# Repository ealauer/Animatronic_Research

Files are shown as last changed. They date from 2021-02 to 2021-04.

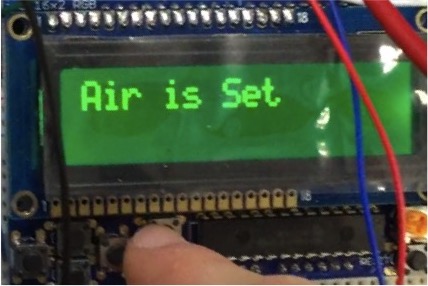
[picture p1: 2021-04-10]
UI Flow Pictures/5AirSet.jpg

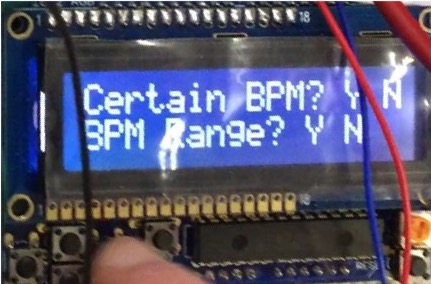
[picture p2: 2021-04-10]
UI Flow Pictures/6Pulse.jpg

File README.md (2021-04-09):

# Humanoid Animatronic Learning Simulator for Medical Interactive Training (H.A.L. S.M.I.T., or HAL for short)
Created by Ethan Lauer, Master of Science Robotics Engineering, Class of 2021, Worcester Polytechnic Institute (WPI)

Advised by Professor Pradeep Radhakrishnan, Department of Mechanical and Robotics Engineering, Worcester Polytechnic Institute (WPI)

Last Edited Spring 2021.

# Introduction
Medical simulation is becoming more prominent in the medical community as it provides a highly realistic and beneficial training experience. The technology is expensive for low-budget medical programs, and manikins have limited capacity for complex tasks. This project addressed such gaps by producing a low-cost head and neck animatronic prototype capable of performing complex simulations. The target simulations for the manikin included airway management, level of consciousness testing, and circulatory assessment. Major facial features were designed so the mechanical systems could exhibit anthropomorphic characteristics. Sensors were integrated into the design, allowing the animatronic to detect and react to changes in the surrounding environment. The subsystems were constructed and tested, however, challenges were faced during full assembly. Despite these challenges, the design demonstrates the potential for a similar application in the medical field. This GitHub repository contains the code, circuit diagrams, and CAD files for HAL.

# Initial Information
Be sure to install the latest version of Arduino (https://www.arduino.cc/en/software) and the Teensy Loader (https://www.pjrc.com/teensy/loader.html) before uploading the code.

Follow the steps detailed in the manual and note the comments in the official when working on H.A.L.

# Folder Descriptions
The folder titled "HAL" contains all of the Arduino code to control HAL.

The folder titled "MATLAB" contains the code and calculations for the possible Stewart platform neck design. This also includes the resulting plots and .xls files of the servo angles necessary for various movements.

The folder titled "New Neck Test" contains area where Arduino code could be developed for the Stewart platform.

The "WaveFilePlayerV1" folder contains the test file for playing pre-recorded audio from a microSD card in the Teensy using the Audio Library.

The folder titled "SolidWorks Files" contains the CAD files for the full system. The Skin CAD files are very large and can be found here (https://drive.google.com/drive/folders/1OjMSTwuhYAyCOeIsZ3wJBqHO3pZZC7u_?usp=sharing).

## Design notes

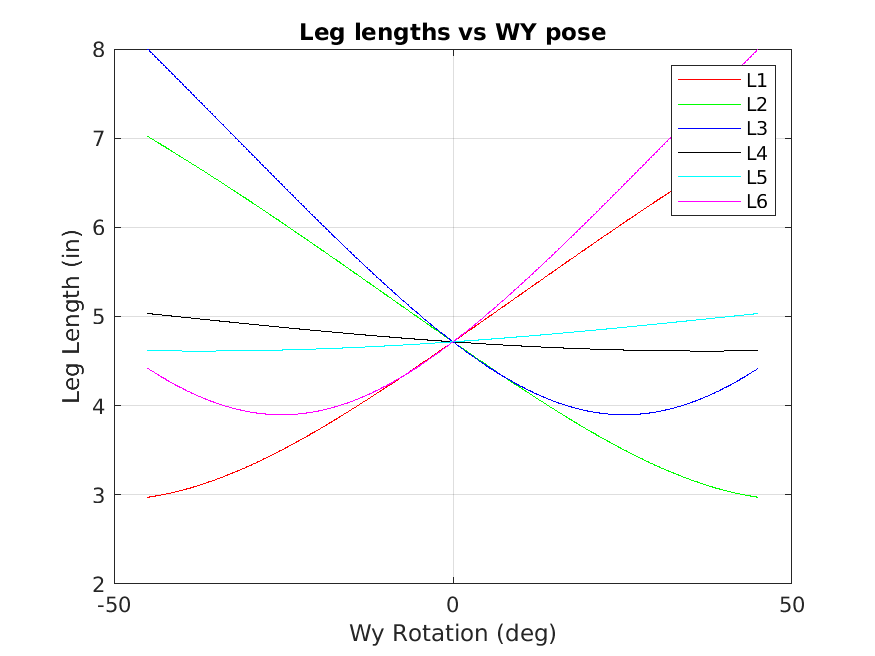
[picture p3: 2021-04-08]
MATLAB/figLegLengthWYPose.png

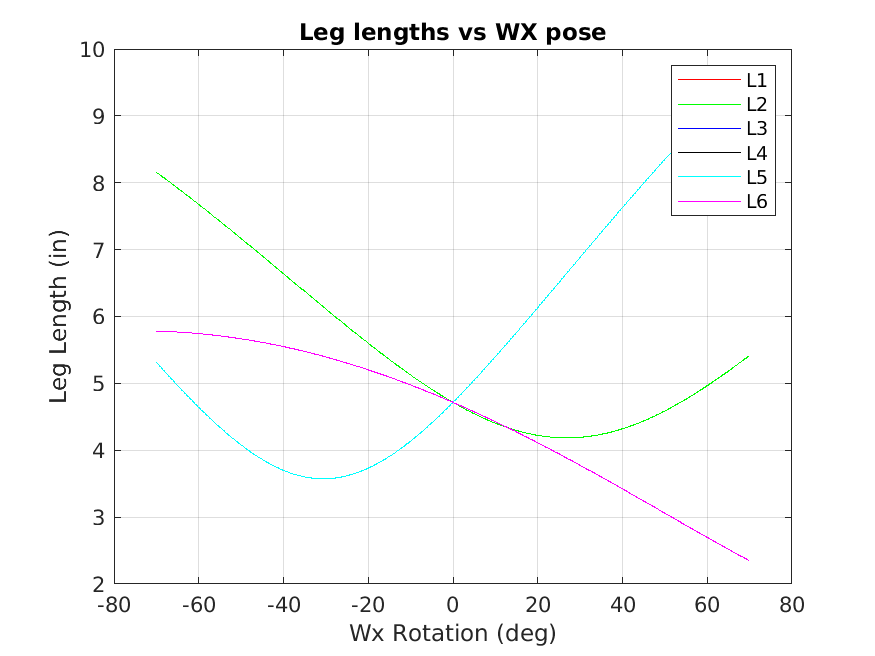
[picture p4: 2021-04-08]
MATLAB/figLegLengthWXPose.png

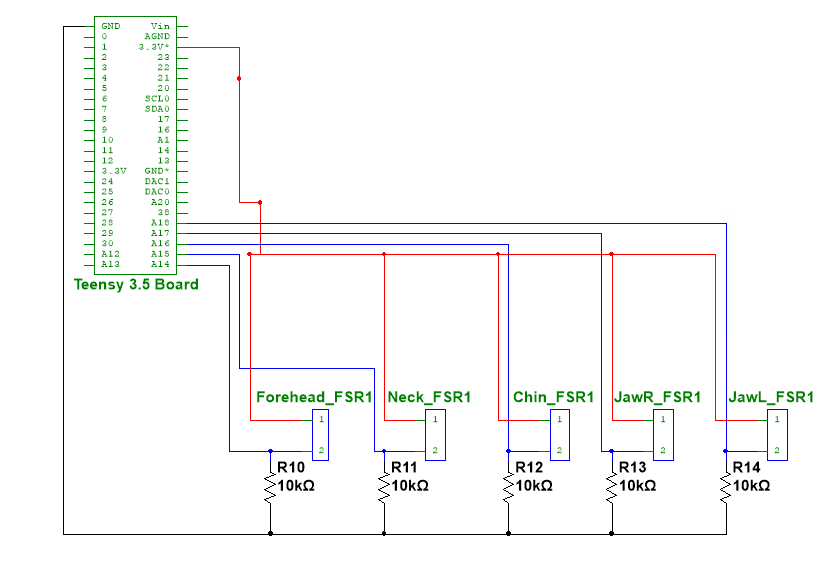
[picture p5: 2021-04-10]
Circuit Diagram Final/Circuit Diagram FSR copy.png

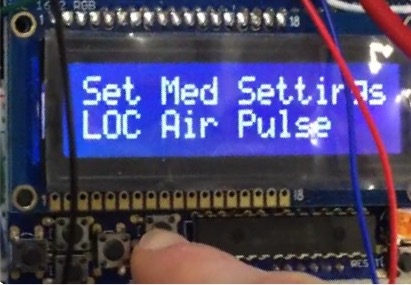
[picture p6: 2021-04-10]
UI Flow Pictures/1Main.jpg

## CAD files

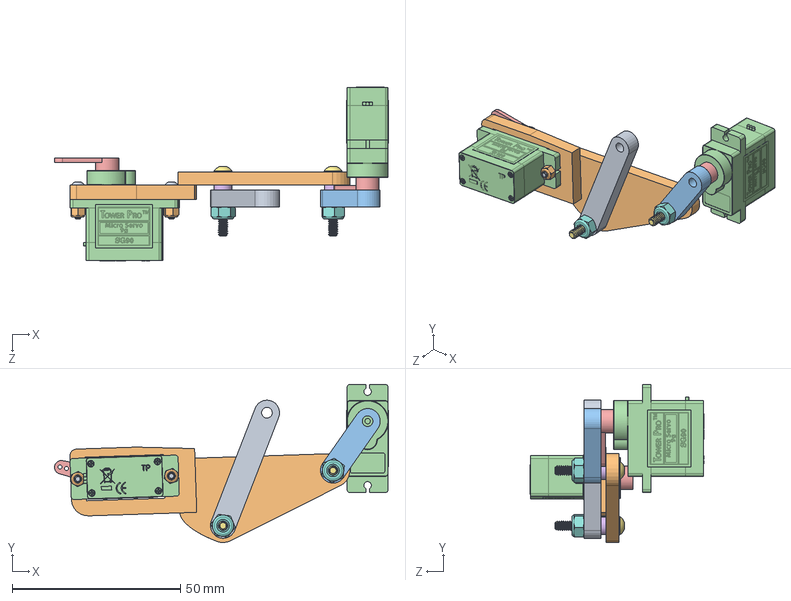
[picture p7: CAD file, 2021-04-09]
SolidWorks Files/Jaw/Jaw Thrust Linkage/LinkageAssemWithServo.SLDASM
99.2 x 47.0 x 51.7 mm
Driven2
TriangleEditedLeft
Driving
SG90 - Micro Servo 9g - Tower Pro.1 x 2
SG90 - Micro Servo 9g - Tower Pro.2 x 2
90295A341_NYLON FLAT WASHER x 2
92949A113_18-8 SS BUTTON HEAD HEX DRIVE SCREW x 2
91831A005_TYPE 18-8 STAINLESS STL NYLON-INSERT LOCKNUT x 2
92095A104_BUTTON HEAD HEX DRIVE SCREW x 2
93625A101_TYPE 18-8 STAINLESS STL NYLON-INSERT LOCKNUT x 2

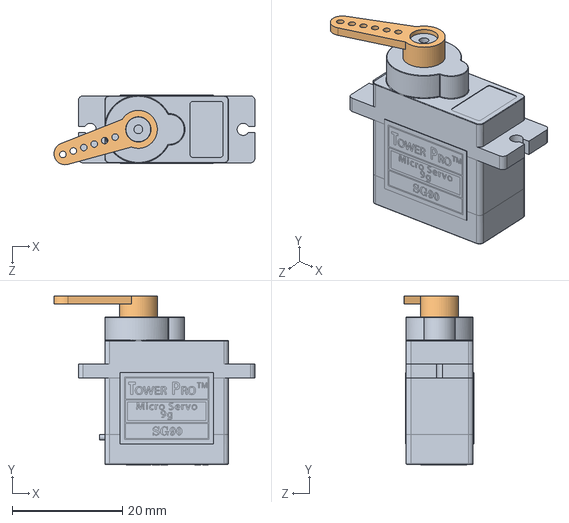
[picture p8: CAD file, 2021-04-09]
SolidWorks Files/Jaw/sg90-micro-servo-9g-tower-pro-1.snapshot.3/ServoSingleHorn.SLDASM
36.5 x 30.6 x 12.6 mm
SG90 - Micro Servo 9g - Tower Pro.1
SG90 - Micro Servo 9g - Tower Pro.2

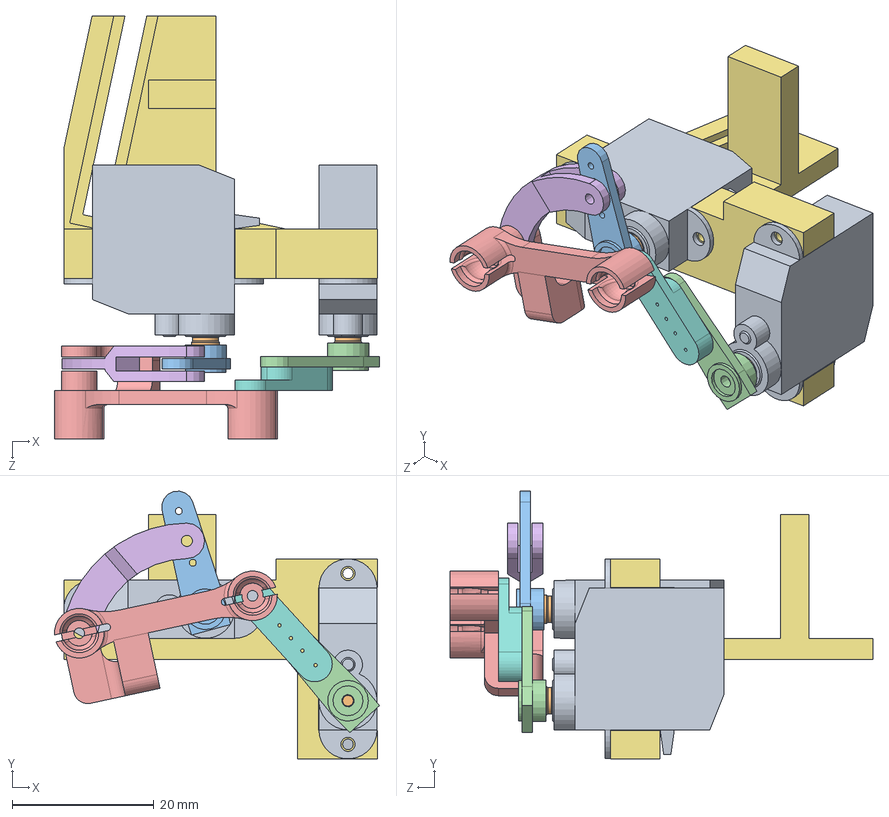
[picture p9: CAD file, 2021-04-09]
SolidWorks Files/Eyebrows/Left Eyebrow/march16 eyebrow.SLDASM
45.8 x 37.8 x 59.6 mm
D56MG Servo Case x 2
D56MG Servo Shaft x 2
drilled and trimmed servo horn
Servo horn trimmed
brow link v2
middle link eyebrow v2
v9 eyebrowbaseleft
20mm extension link

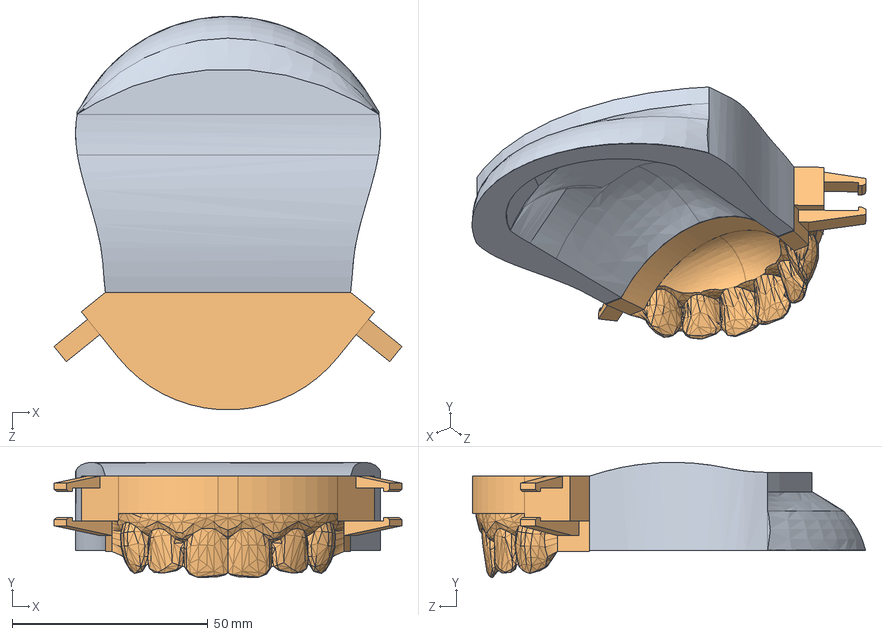
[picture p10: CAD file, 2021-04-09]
SolidWorks Files/Jaw/Updated Cavity and Teeth CAO 15 Nov.SLDASM
88.8 x 29.4 x 100.3 mm
Oral Roof
Top Teeth CAO 4 Nov

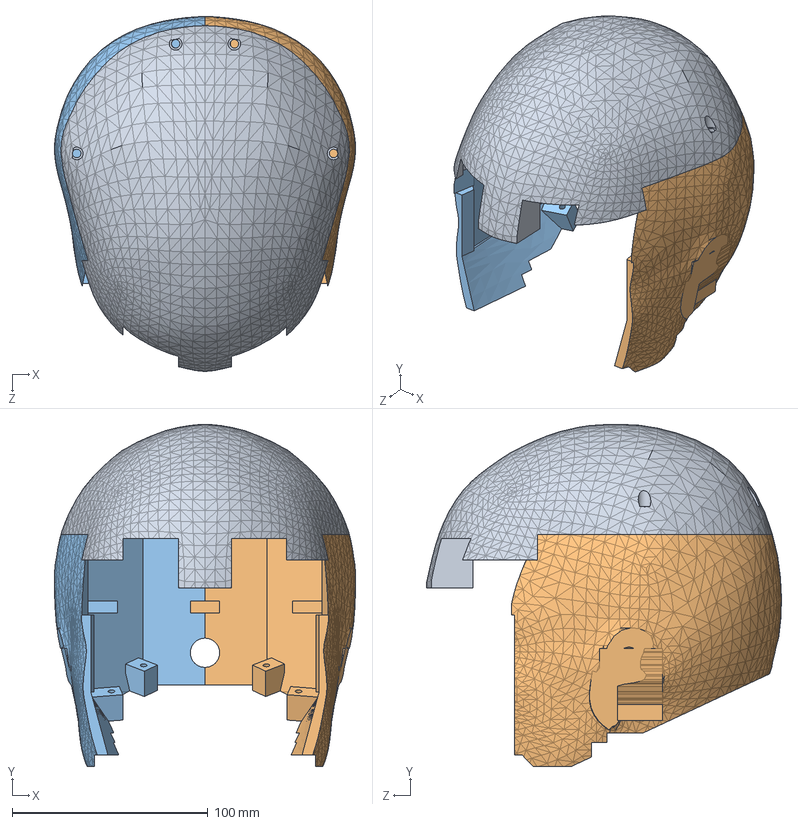
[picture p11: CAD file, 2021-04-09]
SolidWorks Files/Lattice/HeadLatticeAssem.SLDASM
153.8 x 174.7 x 181.3 mm
TopHeadLattice
LeftHeadLattice
RightHeadLattice

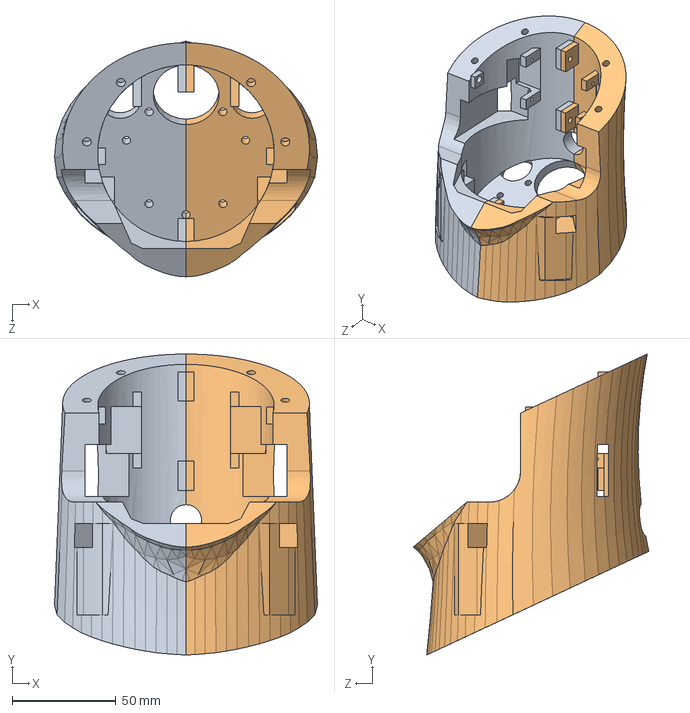
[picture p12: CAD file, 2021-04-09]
SolidWorks Files/Lattice/NeckLatticeAssem.SLDASM
126.6 x 144.9 x 113.4 mm
NeckLatticeRight
NeckLatticeLeft

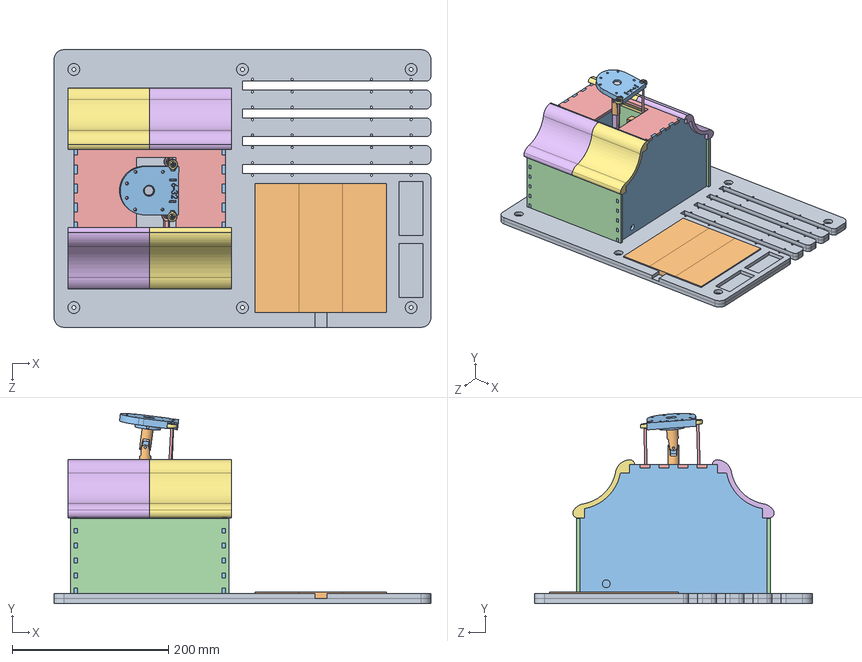
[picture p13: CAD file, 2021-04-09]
SolidWorks Files/Neck/Neck Enclosure/Updated Base.SLDASM
482.6 x 243.5 x 355.6 mm
Base x 2
breadboard Updated x 3
Front Plate x 2
Side Plates x 2
Top Actual
SHOULDER (NO HOLE Right) x 2
SHOULDER (NO HOLE) x 2
6383K245_BALL BEARING x 2
Rotating Plate
Driver x 2
Ball Joint Rod x 4
Ball x 4
Ball Joint x 2
Servo Stand-In x 3
Male Ball Joints x 2
Servo Linkage x 2
Gasket Rod
Servo Block x 4
Block
Stationary Base
Stationary Base Actual V2
Ball Rod x 3
Ball Bearing x 3
94589A200_MIL SPEC. ALUMINUM FLAT WASHER
91099A215_18-8 SS FLAT UNDERCUT HEAD PHIL MACHINE SCREW
91290A174_BLACK-OXIDE CLASS 12.9 SOCKET HEAD CAP SCREW x 4
Upper Plate
Shaft Servo Interfae
Connecting Rod x 2
Shaft

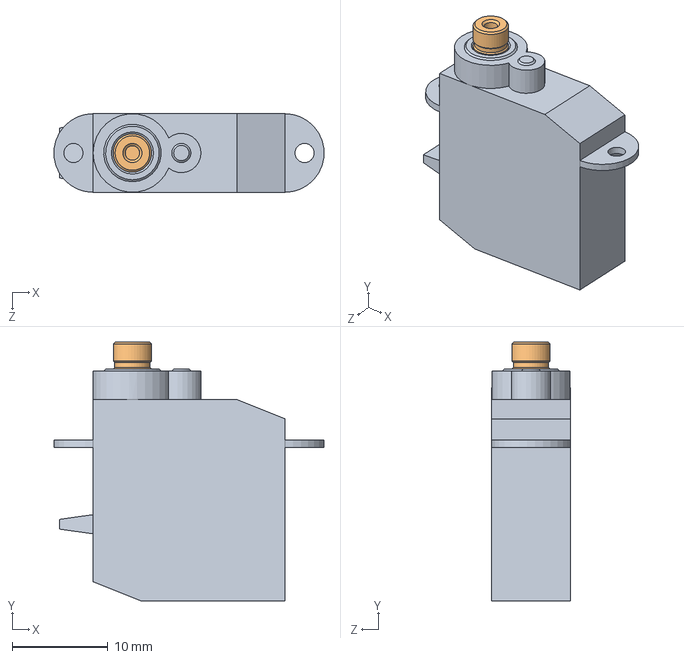
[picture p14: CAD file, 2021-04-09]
SolidWorks Files/Eyebrows/Left Eyebrow/D56MG Servo Assembly.SLDASM
28.2 x 27.0 x 8.20 mm
D56MG Servo Case
D56MG Servo Shaft

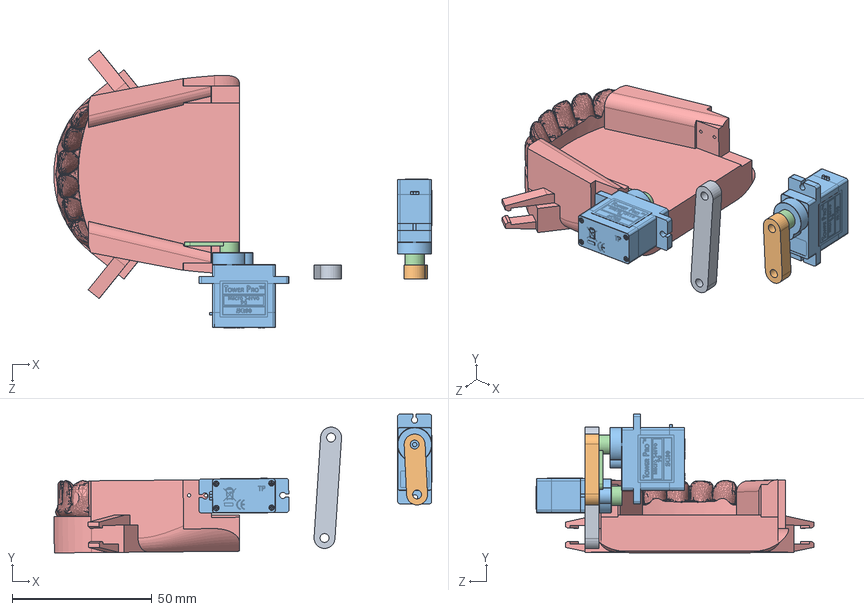
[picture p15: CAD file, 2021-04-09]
SolidWorks Files/Jaw/Jaw Thrust Linkage/LinkageAssemServoBotTeethLeft.SLDASM
135.2 x 49.7 x 99.3 mm
Driven2
Driving
SG90 - Micro Servo 9g - Tower Pro.1 x 2
SG90 - Micro Servo 9g - Tower Pro.2 x 2
Bottom Teeth CAO 4 Nov

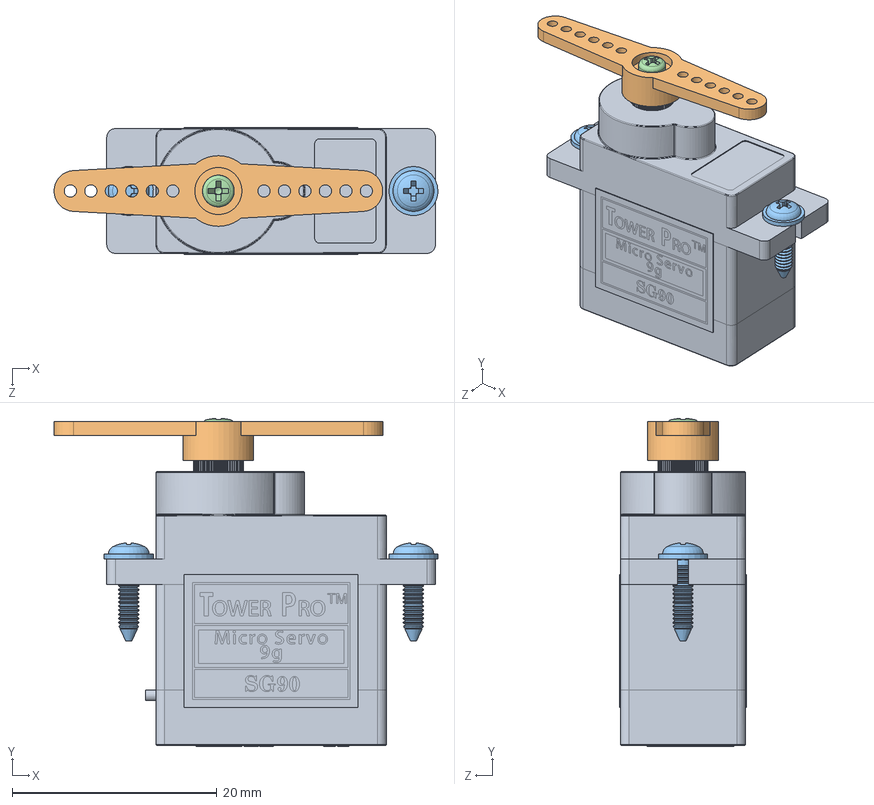
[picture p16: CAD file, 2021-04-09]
SolidWorks Files/Jaw/sg90-micro-servo-9g-tower-pro-1.snapshot.3/SG90 - Micro Servo 9g - Tower Pro.SLDASM
37.5 x 32.0 x 12.4 mm
SG90 - Micro Servo 9g - Tower Pro.1
SG90 - Micro Servo 9g - Tower Pro.3
SG90 - Micro Servo 9g - Tower Pro.5 x 2
SG90 - Micro Servo 9g - Tower Pro.6

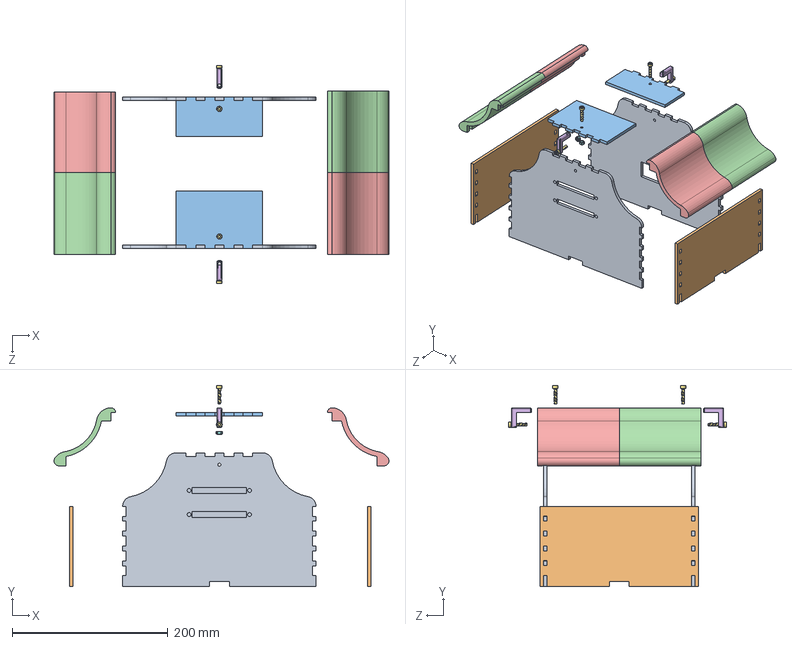
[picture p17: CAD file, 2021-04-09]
SolidWorks Files/Neck/Neck Enclosure/Neck Wood.SLDASM
429.8 x 258.0 x 280.1 mm
Back Plate x 2
Side Plates x 2
Top Actual
SHOULDER (NO HOLE) x 2
SHOULDER (NO HOLE Right) x 2
Lattice Retainer x 2
90128A216_ZNC-PLTD ALLOY STL SCKT HEAD CAP SCREW x 4
90592A090_STEEL HEX NUT x 4

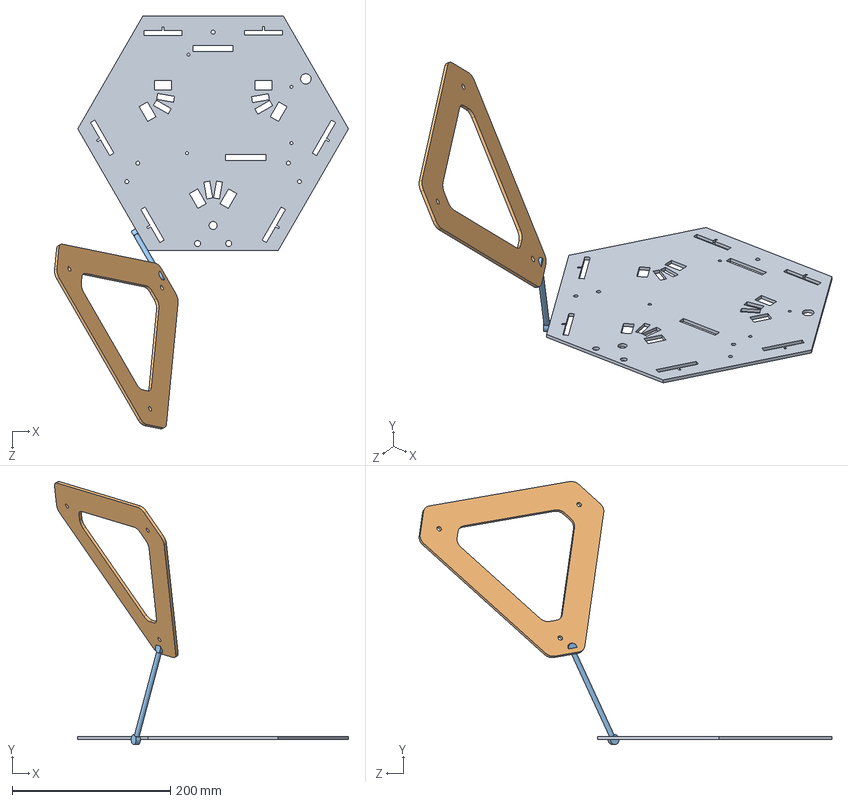
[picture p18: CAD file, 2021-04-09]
Stewart Platform Initial Designs/test assembly.SLDASM
371.8 x 332.8 x 522.1 mm
botplatformsketch
top platform sketch
rod

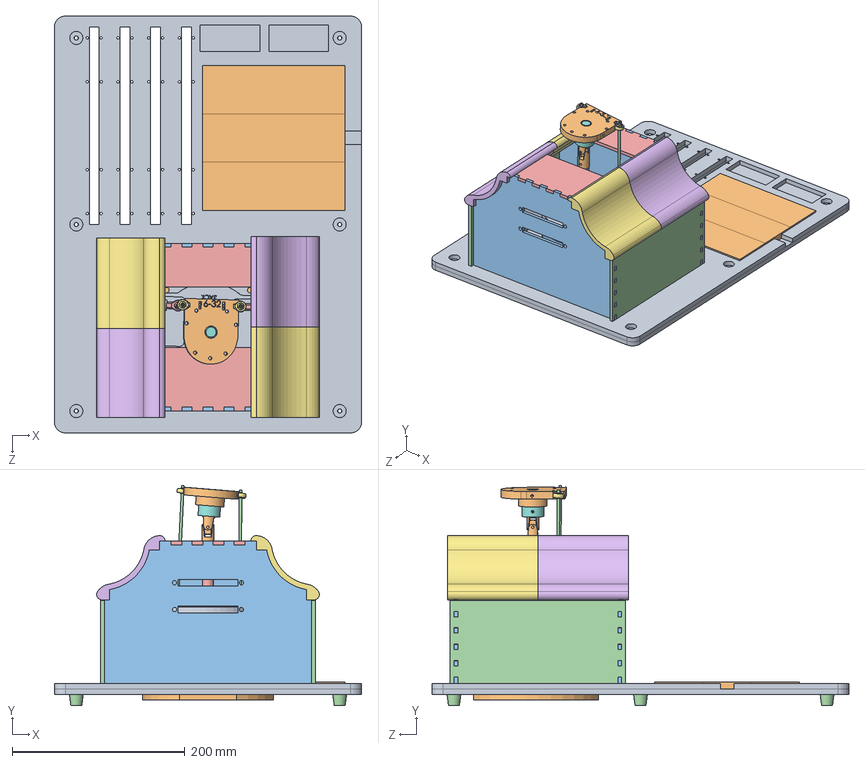
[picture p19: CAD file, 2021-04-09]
SolidWorks Files/Neck/Neck Enclosure/Full Neck and Base Assembly.SLDASM
355.6 x 255.0 x 482.6 mm
Base x 2
breadboard Updated x 3
Back Plate x 2
Side Plates x 2
Top Actual
SHOULDER (NO HOLE) x 2
SHOULDER (NO HOLE Right) x 2
6383K245_BALL BEARING x 2
Rotating Plate
Driver x 2
Ball Joint Rod x 4
Ball x 4
Ball Joint x 2
Servo Stand-In x 3
Male Ball Joints x 2
Gasket Rod
Servo Block x 4
Block
Stationary Base
Stationary Base Actual V2
Ball Rod x 3
Ball Bearing x 3
94589A200_MIL SPEC. ALUMINUM FLAT WASHER x 2
91099A215_18-8 SS FLAT UNDERCUT HEAD PHIL MACHINE SCREW x 2
91290A174_BLACK-OXIDE CLASS 12.9 SOCKET HEAD CAP SCREW x 4
Upper Plate
Shaft Servo Interfae
Connecting Rod x 2
Shaft
Savr x 2
Rotational Saver x 2
Rod Rotation
Servo Linkage3 x 2
Botttom Support
Cover
Stands x 6

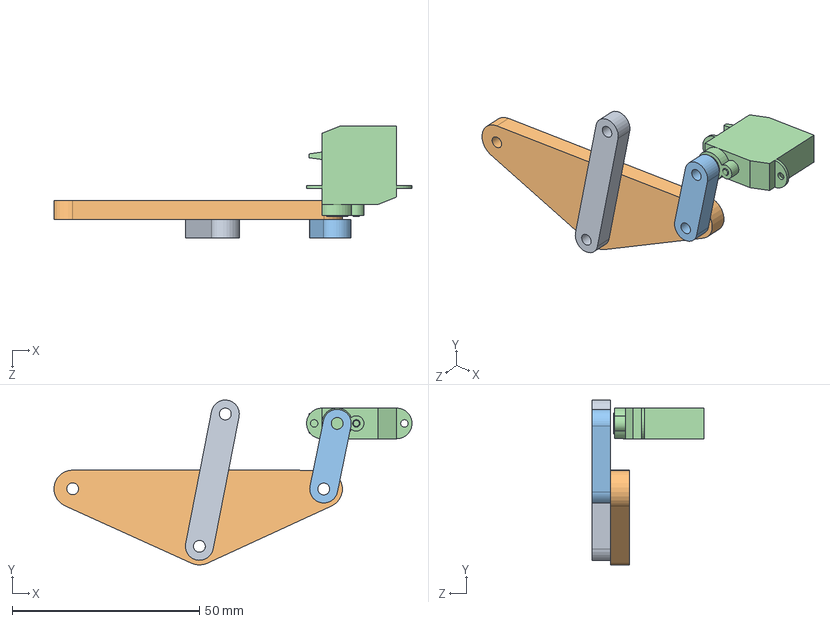
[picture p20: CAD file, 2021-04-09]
SolidWorks Files/Jaw/Jaw Thrust Linkage/LinkageAssem.SLDASM
95.6 x 44.1 x 30.0 mm
Driven2
Driven1
Driving
D56MG Servo Case

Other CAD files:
SolidWorks Files/LinkageAssemWithServo.SLDASM
SolidWorks Files/Eyebrows/Right Eyebrow/Right Eyebrow.SLDASM
SolidWorks Files/march16 eyebrow.SLDASM
SolidWorks Files/Jaw/Jaw Thrust Linkage/LinkageAssemWithServoRight.SLDASM
SolidWorks Files/20mm extension link.SLDPRT
SolidWorks Files/6383K245_BALL BEARING.SLDPRT
SolidWorks Files/90128A216_ZNC-PLTD ALLOY STL SCKT HEAD CAP SCREW.SLDPRT
SolidWorks Files/90128A251_ZNC-PLTD ALLOY STL SCKT HEAD CAP SCREW.SLDPRT
SolidWorks Files/90295A341_NYLON FLAT WASHER.SLDPRT
SolidWorks Files/90480A007_LOW-STRENGTH STEEL HEX NUT.SLDPRT
SolidWorks Files/90592A090_STEEL HEX NUT.SLDPRT
SolidWorks Files/91099A215_18-8 SS FLAT UNDERCUT HEAD PHIL MACHINE SCREW.SLDPRT
SolidWorks Files/91251A540_BLACK-OXIDE ALLOY STEEL SOCKET HEAD CAP SCREW.SLDPRT
SolidWorks Files/91290A180_BLACK-OXIDE CLASS 12.9 SOCKET HEAD CAP SCREW.SLDPRT
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

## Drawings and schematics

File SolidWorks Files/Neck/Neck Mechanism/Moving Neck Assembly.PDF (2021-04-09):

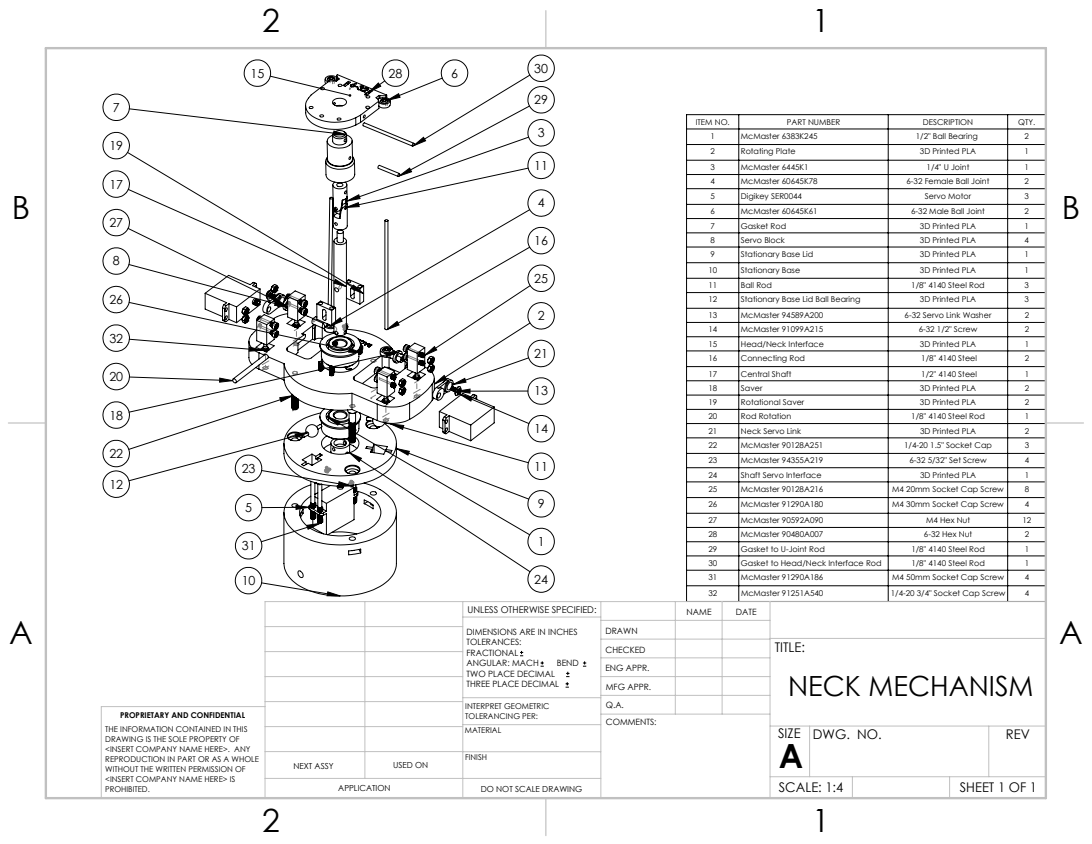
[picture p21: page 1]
ITEM NO.; PART NUMBER; DESCRIPTION; QTY.; McMaster 6383K245; 1/2" Ball Bearing; Rotating Plate; 3D Printed PLA; McMaster 6445K1; 1/4" U Joint; McMaster 60645K78; 6-32 Female Ball Joint; Digikey SER0044; Servo Motor; McMaster 60645K61; 6-32 Male Ball Joint; Gasket Rod; Servo Block; Stationary Base Lid; Stationary Base; Ball Rod; 1/8" 4140 Steel Rod; Stationary Base Lid Ball Bearing; McMaster 94589A200; 6-32 Servo Link Washer; McMaster 91099A215; 6-32 1/2" Screw; Head/Neck Interface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

UNLESS OTHERWISE SPECIFIED: | | NAME | DATE
DIMENSIONS ARE IN INCHES TOLERANCES: FRACTIONAL ANGULAR: MACH BEND TWO PLACE DECIMAL THREE PLACE DECIMAL | DRAWN

CHECKED | | | TITLE: NECK MECHANISM

ENG APPR.
MFG APPR.

INTERPRET GEOMETRIC TOLERANCING PER: | Q.A.

PROPRIETARY AND CONFIDENTIAL
THE INFORMATION CONTAINED IN THIS
DRAWING IS THE SOLE PROPERTY OF
<INSERT COMPANY NAME HERE>. ANY
REPRODUCTION IN PART OR AS A WHOLE
WITHOUT THE WRITTEN PERMISSION OF
<INSERT COMPANY NAME HERE> IS
PROHIBITED.

USED ON | MATERIAL | | SIZE A | DWG. NO. | REV

NEXT ASSY | | FINISH

APPLICATION | DO NOT SCALE DRAWING | | SCALE: 1:4 | | SHEET 1 OF 1

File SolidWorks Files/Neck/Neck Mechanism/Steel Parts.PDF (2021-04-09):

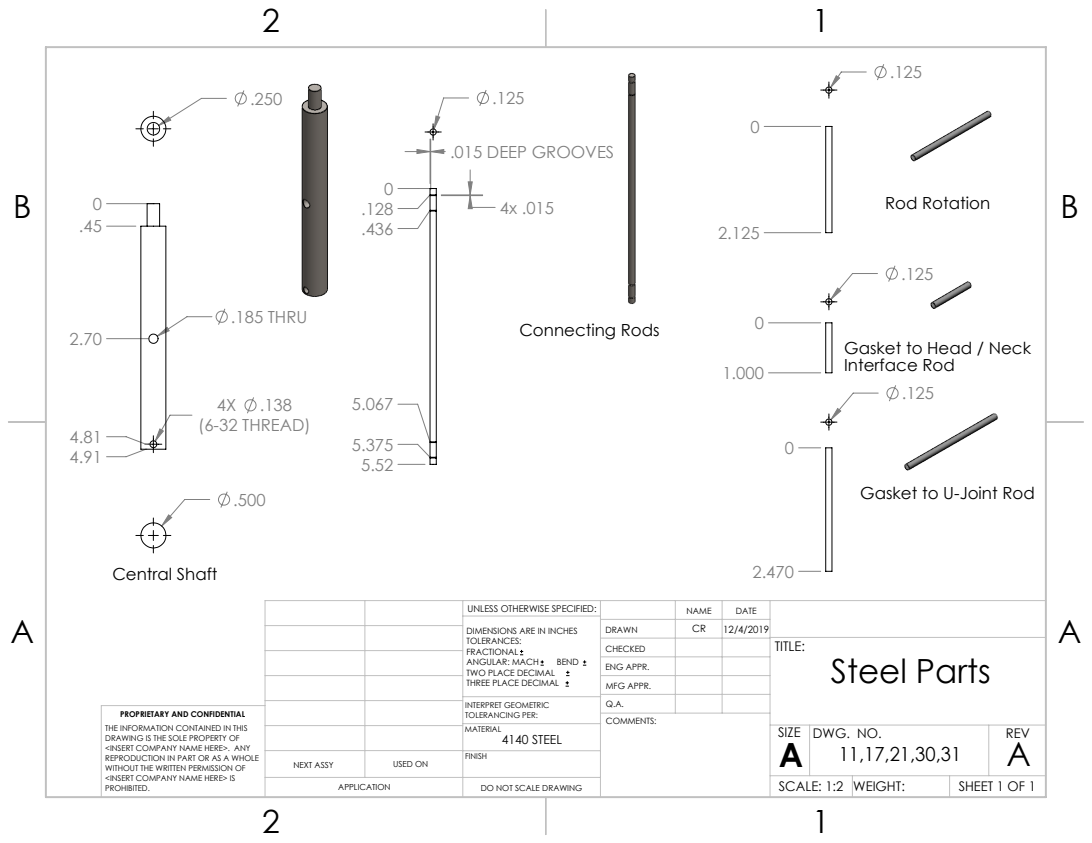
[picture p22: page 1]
4X .138 (6-32 THREAD); .185 THRU; .015 DEEP GROOVES; Central Shaft; Connecting Rods; Rod Rotation

Gasket to Head / Neck
Interface Rod

Gasket to U-Joint Rod

UNLESS OTHERWISE SPECIFIED: | | NAME | DATE
DIMENSIONS ARE IN INCHES TOLERANCES: FRACTIONAL ANGULAR: MACH BEND TWO PLACE DECIMAL THREE PLACE DECIMAL | DRAWN | CR | 12/4/2019

CHECKED | | | TITLE: Steel Parts

ENG APPR.
MFG APPR.

INTERPRET GEOMETRIC TOLERANCING PER: | Q.A.
MATERIAL 4140 STEEL | | SIZE A | DWG. NO. 11,17,21,30,31 | REV A

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

NEXT ASSY | USED ON | FINISH

APPLICATION | DO NOT SCALE DRAWING | | SCALE: 1:2 | WEIGHT: | SHEET 1 OF 1

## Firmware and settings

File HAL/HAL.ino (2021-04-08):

/**********************************************************************************
  HAL.ino

  Animatronic Head Directed Research Spring 2021

  This code is used to control the Humanoid Animatronic Learning Simulator for
  Medical Interactive Training (H.A.L. S.M.I.T., or HAL for short). This is the main
  .ino file that includes all the necessary header files and has the primary switch
  case that controls the overal status of HAL. In this file, the head and display
  objects are created and interact with one another. The display is the user interface
  (UI) that is used to set the three different settings (Level of Conciousness - LOC,
  Airway - Air, Circulation - Pulse). The first few states are where Head's state
  variables are set by the UI. The final "StartSimulationState" is where the head
  completes the desired test. The "head.LOCTEST()" function runs the LOC test with
  all the setting in place for all tests (LOC, Airway, and Circulation). Therefore,
  once the LOC test is complete, HAL will be idleing and the user can perform the
  Airway and Circulation tests. Due to time constraints and unforeseen circumstances,
  there is not a built in feature that ends the simulation. Several of the Serial.print
  messages can be commented out without affecting the code but are very useful
  when debugging.

  Created by Ethan Lauer on 10/3/19
  Last Edited by Ethan Lauer on 4/8/21
*********************************************************************************/

//Include Libraries
#include <Arduino.h>
#include <Wire.h>
#include <Adafruit_PWMServoDriver.h>
#include <Adafruit_RGBLCDShield.h>
#include <utility/Adafruit_MCP23017.h>
#include <Audio.h>
#include <SPI.h>
#include <SD.h>
#include <SerialFlash.h>

//Include Header Files and Necessary Classes
#include "pinSetUp.h"
#include "helperFunctions.h"
#include "head.h"
#include "userInterface.h"

//Create Head and UI Objects
Head head = Head();
Display LCD = Display();

// State Vairable for the Overall System (Comment out the state that is not being used)
// The StartSimulationState is used for skipping past the user input and only uses default values.
// Case variables are defined as globals (see pinSetUp.h).
volatile byte state = PreSimulationState; // For Full Code
//volatile byte state = StartSimulationState; // For Skipping to a Test

// Set up - runs once on start up
void setup() {
  Serial.begin(9600);
  Serial.println("Initializing HAL's Brain...");

  //Start the PWM servos
  pwm0.begin();
  pwm1.begin();
  pwm2.begin();
  pwm3.begin();
  //this is the mx PWM freq
  pwm0.setPWMFreq(60);  // Analog servos run at ~60 Hz updates
  pwm1.setPWMFreq(60);
  pwm2.setPWMFreq(60);
  pwm3.setPWMFreq(60);

  //Set up and initialize the head and LCD
  head.setUp();
  LCD.setUp();

}


// Loop runs infinitly
void loop() {

  //Define variables for columns and rows.
  //These variables will change as the code progresses.
    int *cell;
    int column;
    int row;

    switch (state) {
    case PreSimulationState:    //************************************** PRE SIMULATION STATE **********************************
      // Check what settings are left and return to the appropriate menu display
      if (head.isAllSet() && startSim == 2) {
        state = CheckStartSimState;
      } else if (head.isAllSet() && startSim == 0) {
        startSim = 2;
        state = StartMenuState;
      } else {
        state = StartMenuState;
      }
      break;

    case StartMenuState:    //************************************** STARTING MAIN MENU**********************************
      LCD.startScreen();
      cell = LCD.checkSelection(false); // Enters While loop waiting for user input
      column = cell[0];
      row = cell[1];
      printColumnRow(column, row);

      // Cursor was on the wrong row
      if (row == 0) {
        Serial.println("Wrong row.");
      }
      // *********If LOC was selected*********
      else if (column == LOCCell && !head.isLOCSet) { // If the LOC was not set yet
        state = LOCSettingState;
        Serial.println("Switch to LOC Set");
      } else if (column == LOCCell && head.isLOCSet) {  // do you actually want to make a change to previously set setting?
        state = LCD.checkIfChangeSettings(LOCSettingState, "LOC");
      }

      // *********If AIRWAY was selected************
      else if (column == airwayCell && !head.isAirSet) { // If Air was not set yet
        state = AirwaySettingState;
        Serial.println("Switch to Airway Set");
      } else if (column == airwayCell && head.isAirSet) {   // do you actually want to make a change to previously set setting?
        state = LCD.checkIfChangeSettings(AirwaySettingState, "Airway");
      }

      // **********If PULSE was selected*********
      else if (column == pulseCell && !head.isPulseSet) { // If Pulse was not Set
        state = PulseSettingState;
        Serial.println("Switch to Pulse Set");
      } else if (column == pulseCell && head.isPulseSet) {// do you actually want to make a change to previously set setting?
        state = LCD.checkIfChangeSettings(PulseSettingState, "Pulse");
      }
      break;

    case LOCSettingState:    //******************************** LOC Setting**********************
      int stateLOC;
      stateLOC = LCD.setLOC();    // get user input
      head.setLOC(stateLOC);      // pass setting into Head Class
      state = PreSimulationState; // return to pre sim state
      break;

    case AirwaySettingState:    //************************************** AIRWAY  Setting**********************************
      Serial.println("Set  Airway");
      boolean *airSettings;
      airSettings = LCD.setAirway();  // get user input
      head.setAir(airSettings);       // pass setting into Head Class
      state = PreSimulationState;     // return to pre sim state
      break;

    case PulseSettingState:     //************************************** PULSE  Setting**********************************
      int *pulseArray;
      pulseArray = LCD.setPulse();          // get user input
      if (pulseArray[0] == 0) {
        head.setPulseBPM(pulseArray[1]);    // pass a certain BPM into Head Class
      } else if (pulseArray[0] == 1) {
        head.setPulseRange(pulseArray[1]);   // pass a BPM range into Head Class
      }
      state = PreSimulationState;           // return to pre sim state
      break;

    case CheckStartSimState:      //************************************** Check to Start SIM**********************************
      if (LCD.checkStartSim()) {    // get user input to check if want to start simulation or go back and change settings
        startSim = 1;
        state = StartSimulationState;
      } else {
        startSim = 0;
        state = PreSimulationState;
      }
      break;

    case StartSimulationState:    //**************************************STARTING SIMULATION**********************************
      // Run the test
    //      head.LOCTEST();

      // The tests below were used for testing each component of the head before
      // integrating it with the rest of the system. To run these, use the "StartSimulationState"
      // for the state of this switch case. Then uncomment any of the functions below. The
      // functions below were used often to test various parts of the code.

      //      head.jawTest();
      //      head.voiceTest();
      //      head.headLoop();
      //      head.fsrTest();
      //      head.pulseTest();
      //      head.followHand();
      //      head.micTest();
      break;
    }

}

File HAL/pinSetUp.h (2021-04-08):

/**********************************************************************************
   Pin Set Up header file
   Created by Ethan Lauer on 8/29/2019
      Edited by Ethan Lauer on 4/8/21

 *********************************************************************************/

// called this way, it uses the default address 0x40
Adafruit_PWMServoDriver pwm0 = Adafruit_PWMServoDriver(0x40);
Adafruit_PWMServoDriver pwm1 = Adafruit_PWMServoDriver(0x41);
Adafruit_PWMServoDriver pwm2 = Adafruit_PWMServoDriver(0x42);
Adafruit_PWMServoDriver pwm3 = Adafruit_PWMServoDriver(0x43);
// you can also call it with a different address you want
//Adafruit_PWMServoDriver pwm = Adafruit_PWMServoDriver(0x41);
// you can also call it with a different address and I2C interface
//Adafruit_PWMServoDriver pwm = Adafruit_PWMServoDriver(&Wire, 0x40);

// Depending on your servo make, the pulse width min and max may vary, you
// want these to be as small/large as possible without hitting the hard stop
// for max range. You'll have to tweak them as necessary to match the servos you
// have!
//#define TOWERPROMIN  100 // this is the 'minimum' pulse length count (out of 4096)
//#define TOWERPROAVE  350
//#define TOWERPROMAX  600 // this is the 'maximum' pulse length count (out of 4096)

#define TOWERPROMIN  250 // this is the 'minimum' pulse length count (out of 4096)
#define TOWERPROAVE  300
#define TOWERPROMAX  450 // this is the 'maximum' pulse length count (out of 4096)

// tower pro min 150 and max is 600
// servo freq 50 (about 50 hz updates)

#define TURNIGYMIN  100 // this is the 'minimum' pulse length count (out of 4096)
#define TURNIGYAVE  350
#define TURNIGYMAX  600 // this is the 'maximum' pulse length count (out of 4096)

// Servos for the stewart platform design. Could also work with the initial linkage neck design too.
#define DATANMIN  90 // This is the 'minimum' pulse length count (out of 4096)
#define DATANMAX  500 // This is the 'maximum' pulse length count (out of 4096)


// *************************SERVO PINS*************
//EYE LIDS
const int botEyelidL = 0;
const int topEyelidL = 1;
const int botEyelidR = 2;
const int topEyelidR = 3;
//EYE BALLS
const int horEyeL = 4;
const int vertEyeL = 5;
const int horEyeR = 6;
const int vertEyeR = 7;
//EYEBROWS
const int medialLeft = 8;
const int lateralLeft = 9;
const int medialRight = 10;
const int lateralRight = 11;
//JAWS
const int jawLVert = 12;// test angles are 20 and 120 (based on test linkage and where servo horn connnected)
const int jawRVert = 13;
const int jawLHor = 14;
const int jawRHor = 15;

//NECK * note: these will change once the new neck design is implemented
const int rightTiltPin = 16;//20
const int leftTiltPin = 17;//21
const int rotPin = 18;//22

//MISC VARIABLES
int motorCommandPause = 5;
int potpin = A19;  // analog pin used to connect the potentiometer


// SERVO TYPES
int turnigy = 0;
int towerpro = 1;
int datan = 2;


//// SOLENIOD PULSE
const int leftPulsePin = 24;
const int rightPulsePin = 25;
unsigned long timeNow = 0;

//SPEAKER
//NEED TO SWAP AUDIO IN AND OUTPUT PINS AND HAVE IT ANALOG STEREO CONNECTION *** REMEMBER TO FIX CIRCUIT DIAGRAM
AudioPlaySdWav    playWav;
AudioOutputAnalogStereo   dacs1;
AudioConnection   patchCord1(playWav, dacs1);
#define SDCARD_CS_PIN BUILTIN_SDCARD

// LCD DEFINITIONS
#define RED 0x1
#define YELLOW 0x3
#define GREEN 0x2
#define TEAL 0x6
#define BLUE 0x4
#define VIOLET 0x5
#define WHITE 0x7

// STATE MACHINE CONSTS
const int PreSimulationState = 0;
const int StartMenuState = 1;
const int LOCSettingState = 2;
const int AirwaySettingState = 3;
const int PulseSettingState = 4;
const int CheckStartSimState = 5;
const int StartSimulationState = 6;

//*********************************************UI CONSTS***************************
//Setting Changes
int changeSetYesCell = 0;
int changeSetNoCell = 5;

//OVERALL
int LOCCell = 0;
int airwayCell = 4;
int pulseCell = 8;
int startSim = 2;   // 2 if you are still changing settings, 0 if want to not do simulation, 1 if you want to start simulation


//LOC
int alertCell = 0;
int verbalCell = 2;
int painCell = 4;
int unrespCell = 6;

// AIRWAY
int yesCol = 0;
int noCol = 5;
int normAirState = 0;
int lockJawState = 1;
int irrBreathState = 2;
int stridBreathState = 3;
int agonGaspState = 4;
int airSetState = 5;


//PULSE
int certOrRangeState = 0;
int certState = 1;
int rangeState = 2;
int pulseSetState = 3;

int certainBPMYes[] = {0, 13};
int rangeBPMYes[] = {1, 11};
int normRangeCell = 0;
int fastRangeCell = 5;
int slowRangeCell = 10;

//****************************************************************SERVO CONSTANTS************************************************


// LEFT EYEBALL
//Up Down Servo Positions
const int leftUpVertEye = 100;
const int leftDownVertEye = 55;
//Left Right Servo Positions
const int leftLeftHorEye = 65;
const int leftRightHorEye = 124;
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

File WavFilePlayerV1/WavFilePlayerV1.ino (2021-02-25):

/***************************************************

  This is an example code from the teensy audio library.

*************************************************************/

/***************************************************
  // Simple WAV file player example
  //
  // Three types of output may be used, by configuring the code below.
  //
  //   1: Digital I2S - Normally used with the audio shield:
  //         http://www.pjrc.com/store/teensy3_audio.html
  //
  //   2: Digital S/PDIF - Connect pin 22 to a S/PDIF transmitter
  //         https://www.oshpark.com/shared_projects/KcDBKHta
  //
  //   3: Analog DAC - Connect the DAC pin to an amplified speaker
  //         http://www.pjrc.com/teensy/gui/?info=AudioOutputAnalog
  //
  // To configure the output type, first uncomment one of the three
  // output objects.  If not using the audio shield, comment out
  // the sgtl5000_1 lines in setup(), so it does not wait forever
  // trying to configure the SGTL5000 codec chip.
  //
  // The SD card may connect to different pins, depending on the
  // hardware you are using.  Uncomment or configure the SD card
  // pins to match your hardware.
  //
  // Data files to put on your SD card can be downloaded here:
  //   http://www.pjrc.com/teensy/td_libs_AudioDataFiles.html
  //
  // This example code is in the public domain.

*************************************************************/

#include <Audio.h>
#include <Wire.h>
#include <SPI.h>
#include <SD.h>
#include <SerialFlash.h>

AudioPlaySdWav playWav;
// Use one of these 3 output types: Digital I2S, Digital S/PDIF, or Analog DAC
AudioOutputAnalogStereo dacs1;           //xy=329,47
//AudioOutputAnalog dacs2;     /      //xy=329,47

//AudioOutputAnalog      audioOutput;

AudioConnection patchCord1(playWav, dacs1);
//AudioConnection patchCor21(playWav, dacs2);

AudioControlSGTL5000 sgtl5000_1;

// Use these with the Teensy 3.5 & 3.6 SD card
#define SDCARD_CS_PIN BUILTIN_SDCARD


int state = 0;
boolean wasPlaying = false;
int playState = 0;

void setup() {
  Serial.begin(9600);

  // Audio connections require memory to work.  For more
  // detailed information, see the MemoryAndCpuUsage example
  AudioMemory(8);

  if (!(SD.begin(SDCARD_CS_PIN))) {
    // stop here, but print a message repetitively
    while (1) {
      Serial.println("Unable to access the SD card");
      delay(500);
    }
  }
}

void playFileLoop(const char *filename) {
  Serial.print("Playing file: ");
  Serial.println(filename);

  // Start playing the file.  This sketch continues to
  // run while the file plays.
  playWav.play(filename);

  // A brief delay for the library read WAV info
  delay(5);

  // Simply wait for the file to finish playing.
  while (playWav.isPlaying()) {
        Serial.println("Still playing");

    // uncomment these lines if you audio shield
    // has the optional volume pot soldered
    //    float vol = analogRead(15);
    //    vol = vol / 1024;
    //     sgtl5000_1.volume(vol);
  }
}


void playFile(const char *filename) {
  Serial.print("Playing file: ");
  Serial.println(filename);

  // Start playing the file.  This sketch continues to
  // run while the file plays.
  playWav.play(filename);

  // A brief delay for the library read WAV info
  delay(5);
}

boolean stillPlaying() {
  return playWav.isPlaying();
}

boolean playFileBool(const char *filename) {
  boolean result;
  if (playWav.isPlaying()) {
    result = true;
  } else {
    Serial.print("Playing file: ");
    Serial.println(filename);

    // Start playing the file.  This sketch continues to
    // run while the file plays.
    playWav.play(filename);

    // A brief delay for the library read WAV info
    delay(5);
    result = false;
  }
  return result;
}



void loop() {
  playFileLoop("HELLO.WAV");
  //  Serial.print("start of loop...... state =");  Serial.println(state);
  //  switch (state) {
  //    case 0:
  //      playFile("HELLO.WAV");
  //      state = 1;
  //      break;
  //
  //    case 1:
  //      boolean isDonePlaying = stillPlaying();
  //      Serial.print("Is the song Still playing = ");      Serial.println(isDonePlaying);
  //
  //      if (!isDonePlaying) {
  //        state = 3;
  //      } else {
  //        state = 1;
  //      }
  //      break;
  //
  //    case 3:
  //      playFile("GHOST.WAV");
  //      Serial.println("FINISHED THE SONG! GOOD FOR YOU!");
  //      delay(5000);
  //      break;
  //  }
  //  Serial.print("END of loop...... state =");  Serial.println(state);

}

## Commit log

2021-02-10 rearrange arduino and matlab code
2021-02-10 testing leg lengths for range of motion with plots
2021-02-11 refined range of motion and decreased leg length by 1 in
2021-02-11 started converting link lengths to servo positions
2021-02-16 servo pwms possible fix
    [HAL.ino, neck.h, pinSetUp.h]
2021-02-18 servo angle calcs, graphs, and xls file
    [thetaWX.xls, thetaWY.xls, thetaWZ.xls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]
2021-02-20 tested all but large servos with big code. responds to current setup
2021-02-23 testing sensors and new breadboarded circuit
2021-02-25 tested speaker, microphone, and camera
2021-03-03 fixing stewart platform matlab calcs to incorportate degrees and other functions
    [degWXNew.xls, degWYNew.xls, degWZNew.xls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]
2021-04-08 commented Arduino code for final submission and checked that it compiled
2021-04-08 commenting the matlab code
    [degWXNew.xls, degWYNew.xls, degWZNew.xls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]
2021-04-09 Uploading Solidworks Files
    [20mm extension link.SLDPRT]
2021-04-09 Adding CAD Files
    [6383K245_BALL BEARING.SLDPRT, 90128A216_ZNC-PLTD ALLOY STL SCKT HEAD CAP SCREW.SLDPRT, 90128A251_ZNC-PLTD ALLOY STL SCKT HEAD CAP SCREW.SLDPRT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]
2021-04-09 stewart platform CAD files
    [base_bot.SLDDRW, base_bot.dxf, base_top.SLDDRW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]
2021-04-09 eyebrow cad
    [20mm extension link.SLDPRT, 20mm extension link.STL, D56MG Servo Assembly.SLDASM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]
2021-04-09 eye cad
    [D56MG Servo Assembly.SLDASM, D56MG Servo Case (1).SLDPRT, D56MG Servo Shaft.SLDPRT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]
2021-04-09 jaw cad
    [90295A341_NYLON FLAT WASHER.SLDPRT, 91831A005_TYPE 18-8 STAINLESS STL NYLON-INSERT LOCKNUT.SLDPRT, 92095A104_BUTTON HEAD HEX DRIVE SCREW.SLDPRT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]
2021-04-09 neck CAD
    [44955K312_HIGH-TEMPERATURE METALLIC GASKET.SLDPRT, 6383K245_BALL BEARING.SLDPRT, 90044A284_BLACK-OXIDE ALLOY STEEL SOCKET HEAD CAP SCREW.SLDPRT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]
2021-04-09 lattice CAD
    [92395A112_BRASS PRESS-FIT EXPANSION INSERT FOR PLASTICS.SLDPRT, HeadLatticeAssem.SLDASM, NeckLatticeAssem.SLDASM]
2021-04-10 circuit diagrams
2021-04-10 UI flow
